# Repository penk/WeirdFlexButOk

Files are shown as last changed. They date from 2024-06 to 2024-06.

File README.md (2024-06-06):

## WeirdFlexButOk 

A hot-swappable unibody ergo split keyboard.

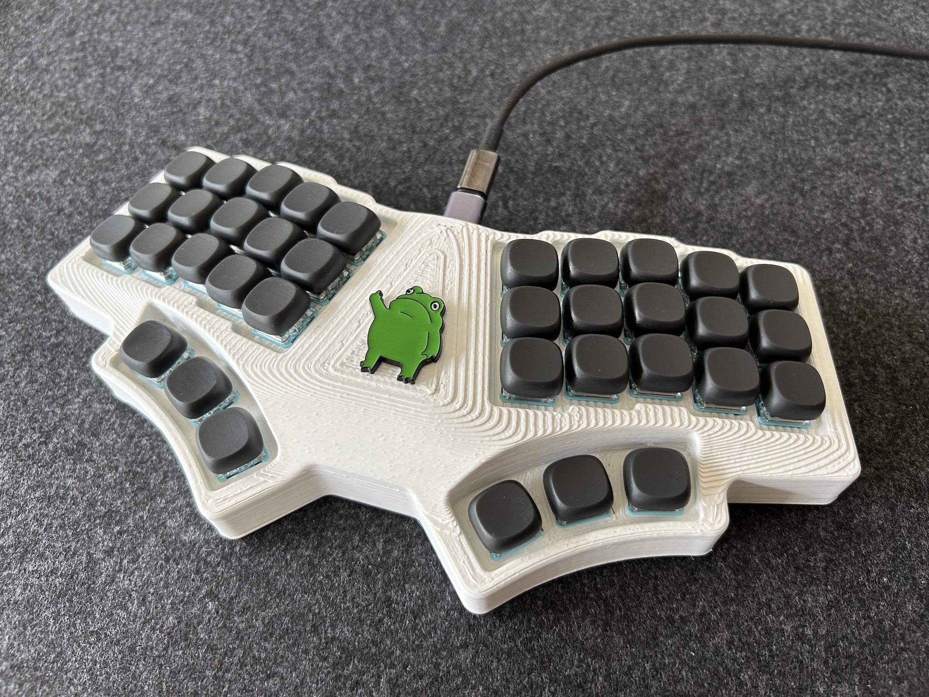
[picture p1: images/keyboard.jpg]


This is inspired by Joe Scotto's handwired [ScottoErgo](https://scottokeebs.com/blogs/keyboards/scottoergo-handwired-keyboard) but opts for Choc spacing and hot-swap sockets, plus a super-bendy 0.8mm PCB with kerf bending cuts. It flexes to follow the case’s contour, providing a 15° tilt and 10° tent from one FR4 PCB. 

## Bill of Materials (BOM)

Quantity | Item 
--- | --- 
1 | RP2040-Zero & Pin headers 
1 | WeirdFlexButOk PCB 
1 | WeirdFlexButOk case & plate
36 | Kailh Choc V1 switches  
36 | Kailh Choc V1 Hot-swap sockets 
36 | 1N4148 diodes (SMD)
2 | WS2812B LEDs (optional, for underglow)
8 | M2x4 heat-set thread inserts
6 | M2x8 standoffs
14 | M2x4 screws 

## Production Files

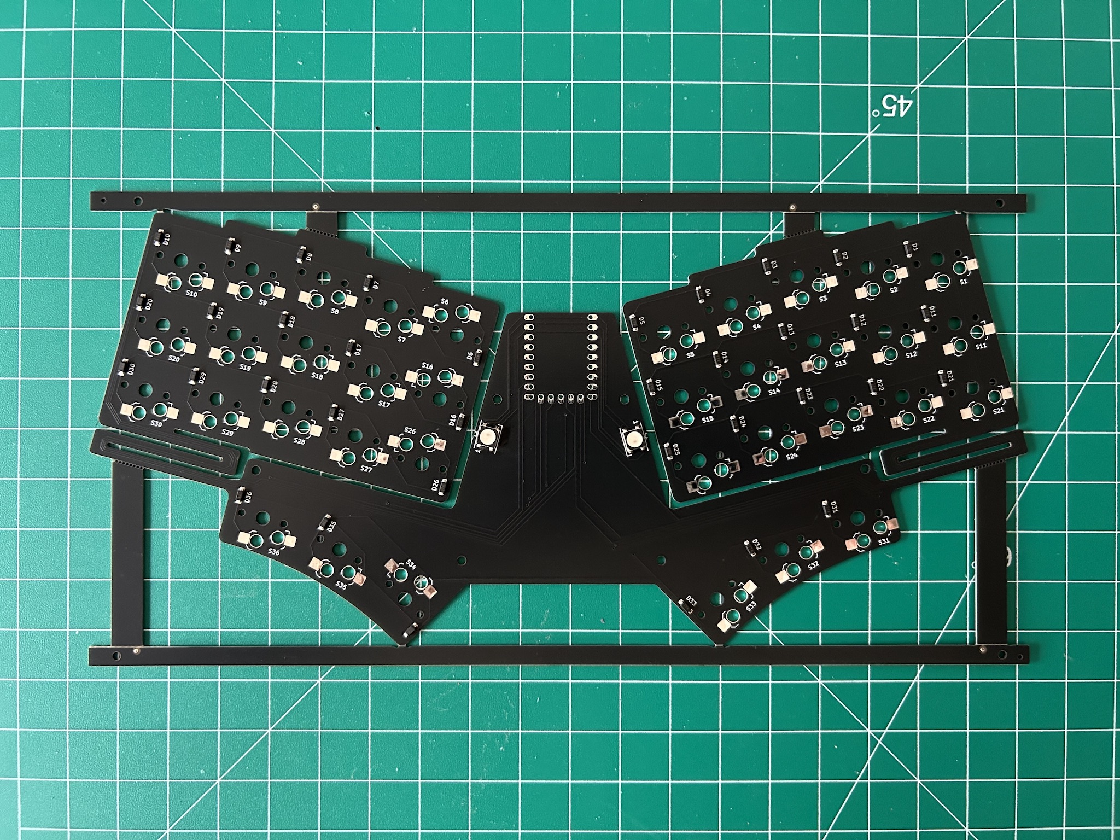
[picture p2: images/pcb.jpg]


To place an order for the WeirdFlexButOk PCB:

- Use the Gerber files in the [production/](production/) folder. 
- Optionally, you can utilize the [BOM](production/BOM.csv) and [CPL](production/CPL.csv) files with a PCBA service. All components (except RP2040-Zero) are soldered to the bottom side of the board.

Make sure to select the following specs so the PCB can flex:

- Base Material: `FR4`
- PCB Thickness: `0.8mm` 

The complete PCB design project is in the [kicad/](kicad/) folder. 

## 3D Printable Files 

3D print the case with the provided [STL files](case/). 

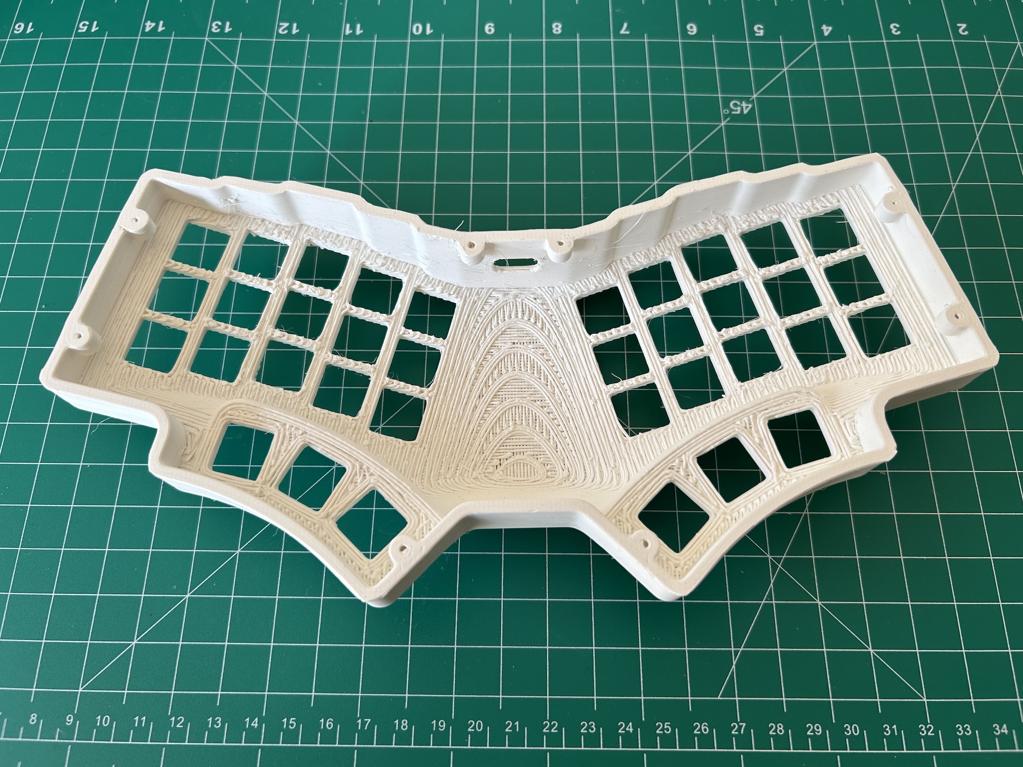
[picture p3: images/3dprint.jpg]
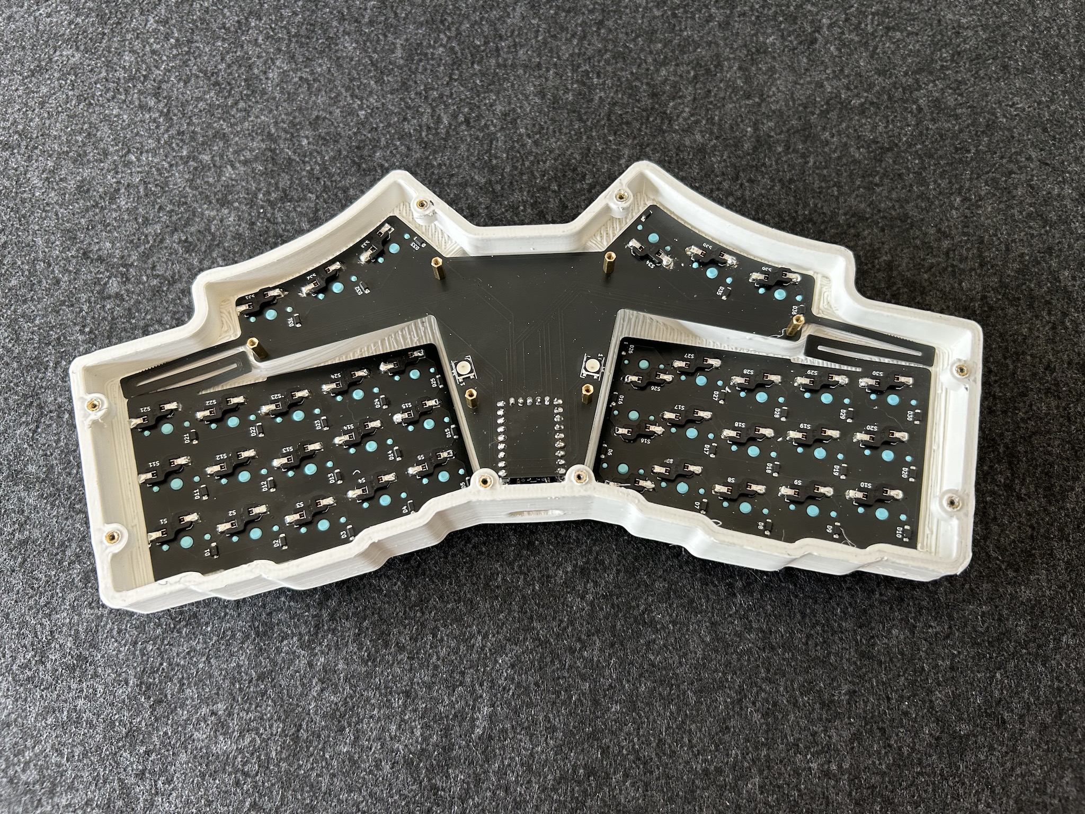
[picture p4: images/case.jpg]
|  |  |
|---|---|

There will be a lot of support materials, and the tolerance needs to be tuned right for the switches (14.2x14.2mm) to fit.

I find the following parameters work best for my print:

- Top/Bottom Speed: 30 mm/s 
- Support Structure: Tree
- Fan Speed Override: True
- Support Skin Fan Speed: 100%

## Firmware 

Precompiled VIA-enabled firmware: 

- Flash [penk_weirdflexbutok36_via.uf2](firmware/penk_weirdflexbutok36_via.uf2) to the RP2040-Zero.
- Load the [via.json](firmware/QMK/keyboards/penk/weirdflexbutok36/via.json) file in `Design` tab for [VIA](https://usevia.app) configuration.

## Keycaps

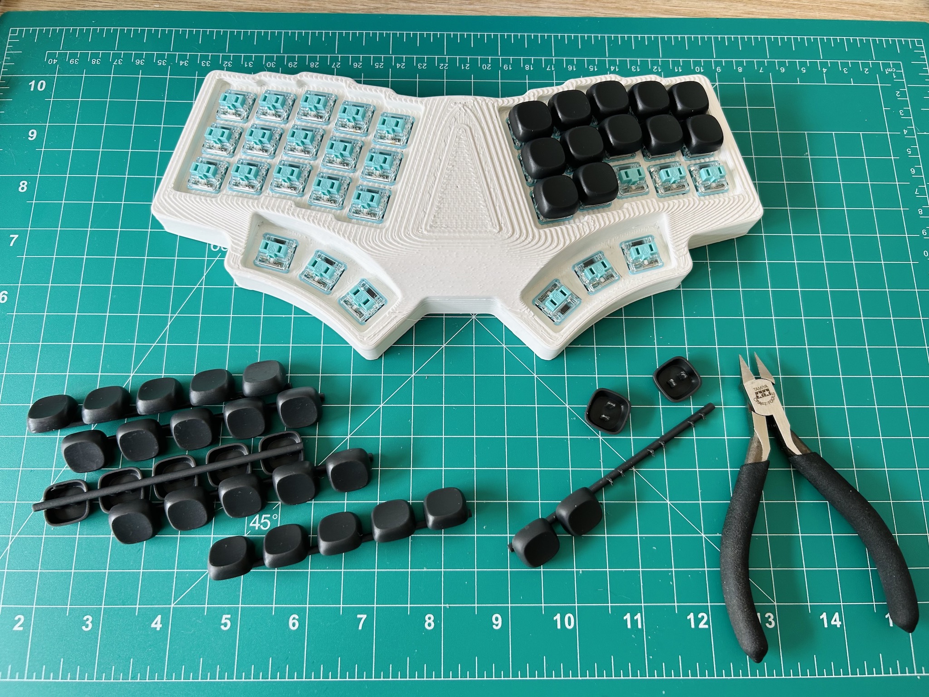
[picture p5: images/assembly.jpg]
Assembly


The keycap featured in this image is designed based on the Shiratama profile by [@taneyats](https://twitter.com/taneyats). The original design can be found [here](https://www.taneyats.com/entry/shiratama-profile), and is licensed for non-commercial use under [CC BY-NC 4.0](https://creativecommons.org/licenses/by-nc/4.0).

### Attribution
- **Author:** [@taneyats](https://twitter.com/taneyats)
- **Source:** [Shiratama keycaps](https://taneyats.booth.pm/items/4020198)
- **License:** [Creative Commons Attribution-NonCommercial 4.0 International](https://creativecommons.org/licenses/by-nc/4.0/)

### Derivative Work
The STL file has been modified for Choc spacing and is available here: [Shiratama-choc-1U-set.stl](keycap/Shiratama-choc-1U-set.stl) (Modification by [@penk](https://github.com/penk)).

This adaptation is intended for personal use only.

## Copyright and License
Copyright (c) 2024 Penk Chen. All rights reserved.

All files, except those specifically mentioned as licensed under Creative Commons, are licensed under the MIT license. For more information, see the [LICENSE](LICENSE).

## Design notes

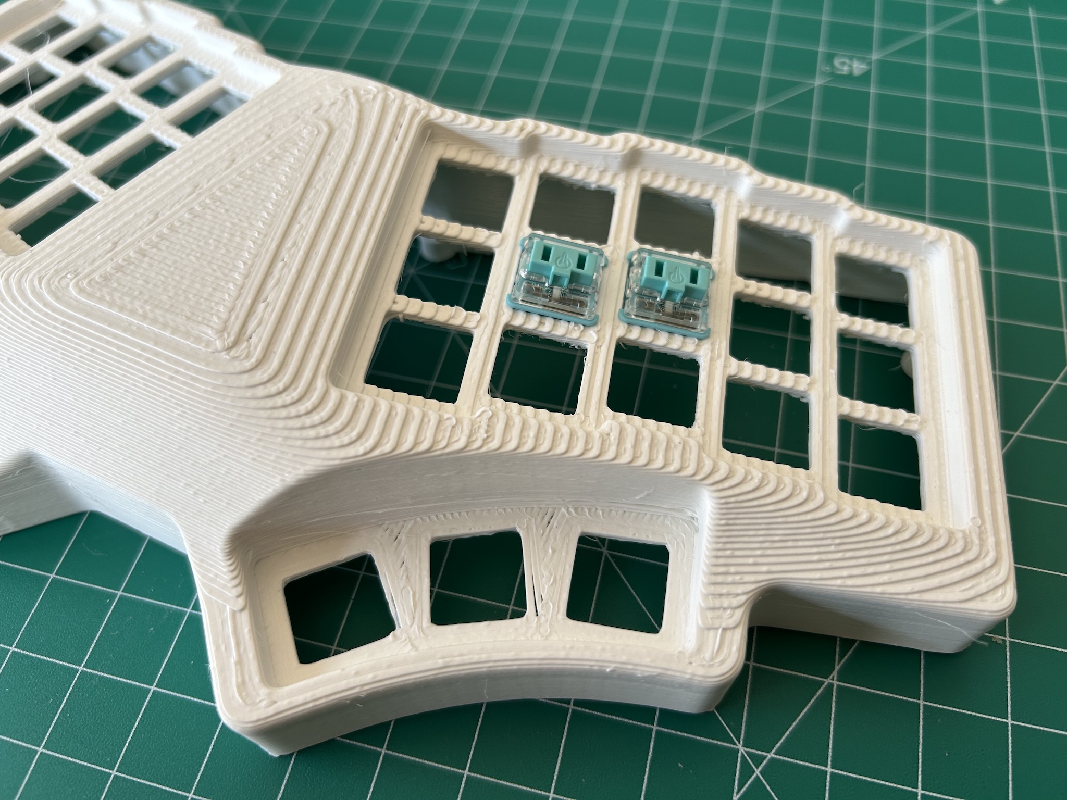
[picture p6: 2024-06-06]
images/tolerance.jpg

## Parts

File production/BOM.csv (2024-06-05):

Designator | Footprint | Quantity | Value | LCSC Part #
D1, D10, D11, D12, D13, D14, D15, D16, D17, D18, D19, D2, D20, D21, D22, D23, D24, D25, D26, D27, D28, D29, D3, D30, D31, D32, D33, D34, D35, D36, D4, D5, D6, D7, D8, D9 | Diode_SOD-123 | 36 | Diode | C2972760
L1, L2 | LED_WS2812B_PLCC4_5.0x5.0mm_P3.2mm | 2 | WS2812B | C2761795
S1, S10, S11, S12, S13, S14, S15, S16, S17, S18, S19, S2, S20, S21, S22, S23, S24, S25, S26, S27, S28, S29, S3, S30, S31, S32, S33, S34, S35, S36, S4, S5, S6, S7, S8, S9 | SW_choc_v1_HS_1u | 36 | Keyswitch | C5333465

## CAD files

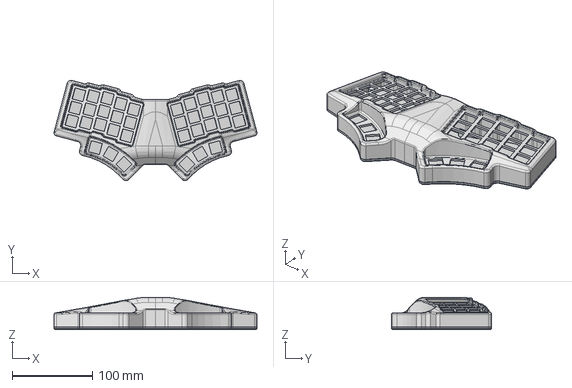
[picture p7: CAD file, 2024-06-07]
case/WeirdFlexButOk-case.step
253.6 x 125.3 x 40.2 mm

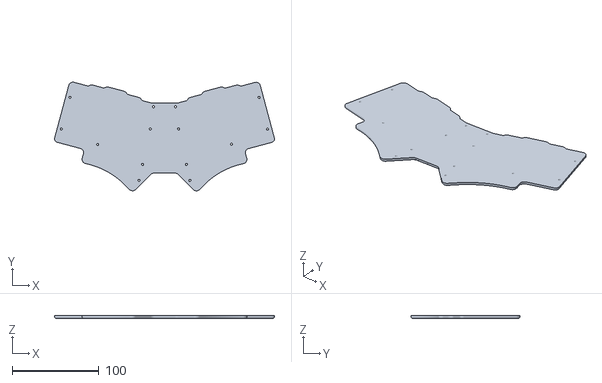
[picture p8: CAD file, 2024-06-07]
case/WeirdFlexButOk-plate.stl
253.6 x 125.3 x 3.00

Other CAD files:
case/WeirdFlexButOk-case.stl

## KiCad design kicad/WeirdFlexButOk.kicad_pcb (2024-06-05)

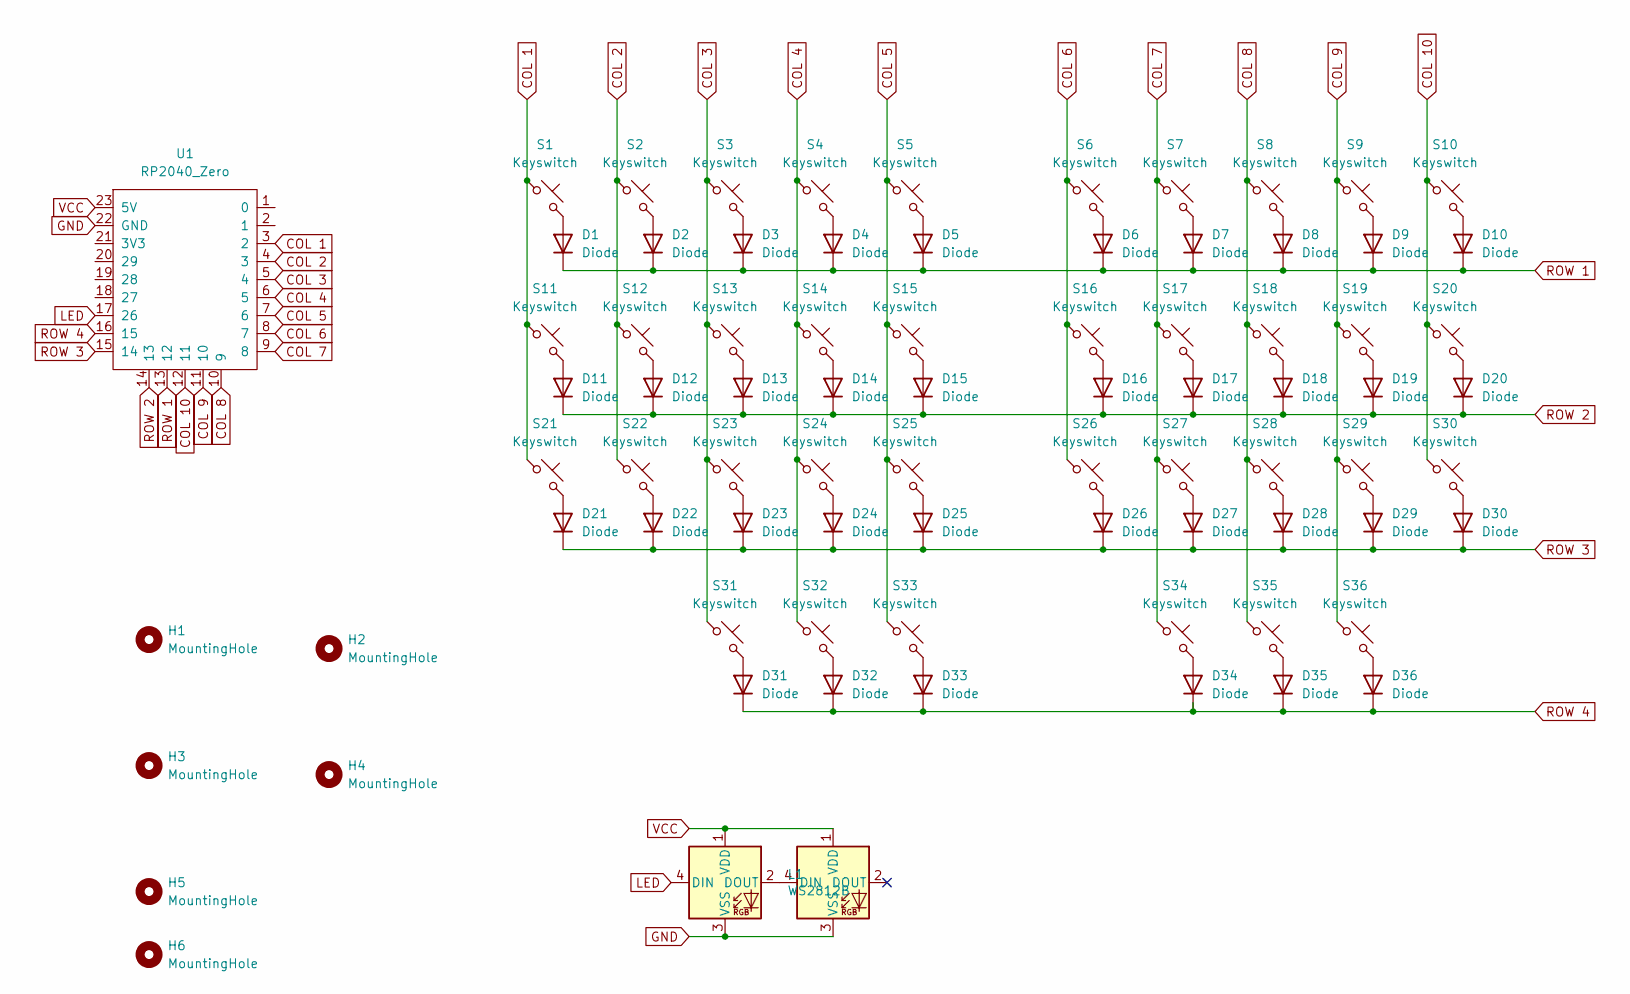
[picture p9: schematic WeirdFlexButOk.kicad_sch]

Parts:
D1, D2, D3, D4, D5, D6, D7, D8, D9, D10, D11, D12, D13, D14, D15, D16, D17, D18, D19, D20, D21, D22, D23, D24, D25, D26, D27, D28, D29, D30, D31, D32, D33, D34, D35, D36: Diode; Diode_SOD-123
H1, H2, H3, H4, H5, H6: MountingHole; MountingHole_2.2mm_M2
L1, L2: WS2812B; LED_WS2812B_PLCC4_5.0x5.0mm_P3.2mm
S1, S2, S3, S4, S5, S6, S7, S8, S9, S10, S11, S12, S13, S14, S15, S16, S17, S18, S19, S20, S21, S22, S23, S24, S25, S26, S27, S28, S29, S30, S31, S32, S33, S34, S35, S36: Keyswitch; SW_choc_v1_HS_1u
U1: RP2040_Zero

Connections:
COL 1: S1.1, S11.1, S21.1, U1.3 (2)
COL 2: S2.1, S12.1, S22.1, U1.4 (3)
COL 3: S3.1, S13.1, S23.1, S31.1, U1.5 (4)
COL 4: S4.1, S14.1, S24.1, S32.1, U1.6 (5)
COL 5: S5.1, S15.1, S25.1, S33.1, U1.7 (6)
COL 6: S6.1, S16.1, S26.1, U1.8 (7)
COL 7: S7.1, S17.1, S27.1, S34.1, U1.9 (8)
COL 8: S8.1, S18.1, S28.1, S35.1, U1.10 (9)
COL 9: S9.1, S19.1, S29.1, S36.1, U1.11 (10)
COL 10: S10.1, S20.1, S30.1, U1.12 (11)
GND: L1.3 (VSS), L2.3 (VSS), U1.22 (GND)
LED: L1.4 (DIN), U1.17 (26)
unnamed: D1.2 (A), S1.2
unnamed: D2.2 (A), S2.2
unnamed: D3.2 (A), S3.2
unnamed: D4.2 (A), S4.2
unnamed: D5.2 (A), S5.2
unnamed: D6.2 (A), S6.2
unnamed: D7.2 (A), S7.2
unnamed: D8.2 (A), S8.2
unnamed: D9.2 (A), S9.2
unnamed: D10.2 (A), S10.2
unnamed: D11.2 (A), S11.2
unnamed: D12.2 (A), S12.2
unnamed: D13.2 (A), S13.2
unnamed: D14.2 (A), S14.2
unnamed: D15.2 (A), S15.2
unnamed: D16.2 (A), S16.2
unnamed: D17.2 (A), S17.2
unnamed: D18.2 (A), S18.2
unnamed: D19.2 (A), S19.2
unnamed: D20.2 (A), S20.2
unnamed: D21.2 (A), S21.2
unnamed: D22.2 (A), S22.2
unnamed: D23.2 (A), S23.2
unnamed: D24.2 (A), S24.2
unnamed: D25.2 (A), S25.2
unnamed: D26.2 (A), S26.2
unnamed: D27.2 (A), S27.2
unnamed: D28.2 (A), S28.2
unnamed: D29.2 (A), S29.2
unnamed: D30.2 (A), S30.2
unnamed: D31.2 (A), S31.2
unnamed: D32.2 (A), S32.2
unnamed: D33.2 (A), S33.2
unnamed: D34.2 (A), S34.2
unnamed: D35.2 (A), S35.2
unnamed: D36.2 (A), S36.2
unnamed: L1.2 (DOUT), L2.4 (DIN)
ROW 1: D1.1 (K), D2.1 (K), D3.1 (K), D4.1 (K), D5.1 (K), D6.1 (K), D7.1 (K), D8.1 (K), D9.1 (K), D10.1 (K), U1.13 (12)
ROW 2: D11.1 (K), D12.1 (K), D13.1 (K), D14.1 (K), D15.1 (K), D16.1 (K), D17.1 (K), D18.1 (K), D19.1 (K), D20.1 (K), U1.14 (13)
ROW 3: D21.1 (K), D22.1 (K), D23.1 (K), D24.1 (K), D25.1 (K), D26.1 (K), D27.1 (K), D28.1 (K), D29.1 (K), D30.1 (K), U1.15 (14)
ROW 4: D31.1 (K), D32.1 (K), D33.1 (K), D34.1 (K), D35.1 (K), D36.1 (K), U1.16 (15)
VCC: L1.1 (VDD), L2.1 (VDD), U1.23 (5V)

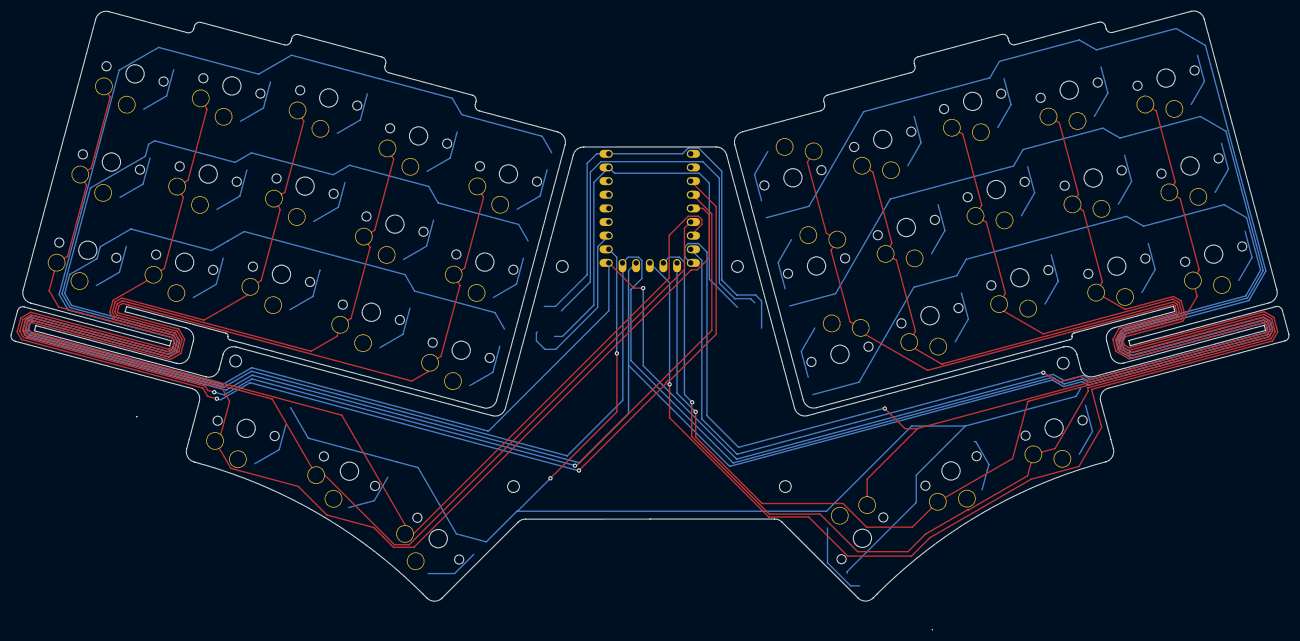
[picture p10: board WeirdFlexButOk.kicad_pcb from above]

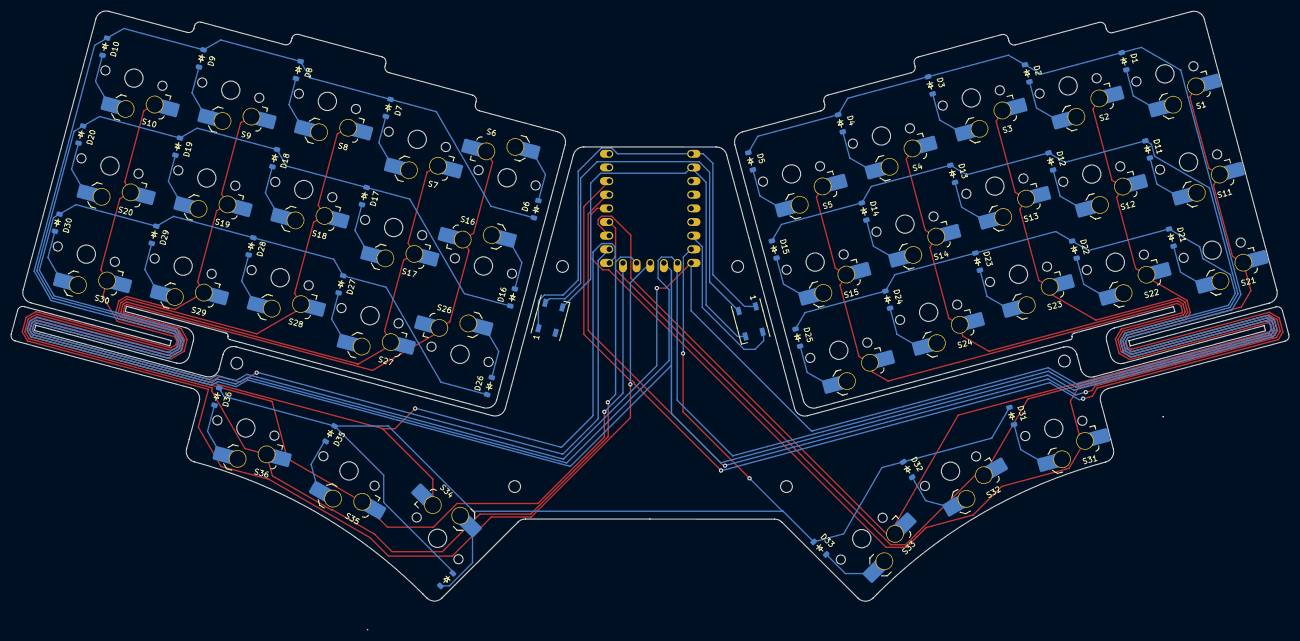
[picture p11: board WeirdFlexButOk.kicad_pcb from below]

Board: 2 copper layers, 238.0 x 115.2 mm, 81 parts (74 on the bottom side), 54 nets.

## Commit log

2024-06-07 Minor tweaks on the case
    [WeirdFlexButOk-case.step, WeirdFlexButOk-case.stl, WeirdFlexButOk-plate.stl]
2024-06-09 Update firmware to use LED vendor driver
